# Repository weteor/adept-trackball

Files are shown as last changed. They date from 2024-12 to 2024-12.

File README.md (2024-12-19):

## xiao-mod changes:

- newly routed pcb ( [KiCAD files](hardware/electronics/adept_xiao) )
  
  - xiao rp2040 controller
  
  - two layer
  
  - components needed:
    
    - 1x seeed xiao rp2040 controller
    
    - 1x xc6206P18 LDO in SOT-23 package
    
    - 1x 100nF capacitor - 0805
    
    - 2x 1uF capacitors - 0805
    
    - 1x 10uF capacitor - 0805
    
    - 1x 39Ohm resistor - 0805
    
    - 1x 10kOhm resistor - 0805
    
    - 1x PMW3360DM-T2QU sensor (same as in orig ploopy adept)
    
    - 6x Omron D2LS-21 switches (same as in orig ploopy adept)

- modified case to support xiao dimensions ( [FreeCAD and STL files](hardware/mechanicals-xiao) )

- firmware modifications to support xiao pinout, copy [folder](firmwares/xiao_mod) to your Vial firmware folder under keyboards/ploopyco and build with: 
  `make ploopyco/adept_xiao:vial`
  or use the  `ploopyco_adept_xiao_rev1_001_vial.uf2` in the folder directly and configure the buttons in vial

---

# The Ploopy Adept Trackball

The Ploopy Adept Trackball

By some stroke of luck, you've made your way here. The Ploopy Adept Trackball. Your life will never be the same.

This repository contains all of the design and production files necessary to make a Ploopy Adept Trackball. We've also included some kick-ass documentation in the Wiki on how to get it made, assemble it, and program it.

What are you waiting for? Your new life awaits.

## QMK?!

Kits bought from the [Ploopy store](https://ploopy.co/product-category/trackball/adept/) come with QMK and VIA preloaded. Check out the Wiki for instructions on how to load new firmware onto your device. (It's super easy!)

The firmware hex file that ships with all Adepts is included in this repository as well, as `ploopyco_madromys_rev1_001_via.uf2`.

## Under what license is this released?

As per QMK's licensing requirements, the firmware for the Ploopy Adept Trackball is released under GPLv3. Hardware design files, including electronics and mechanical files, are released under OHL CERN v2-S. Check the respective directories for full license text.

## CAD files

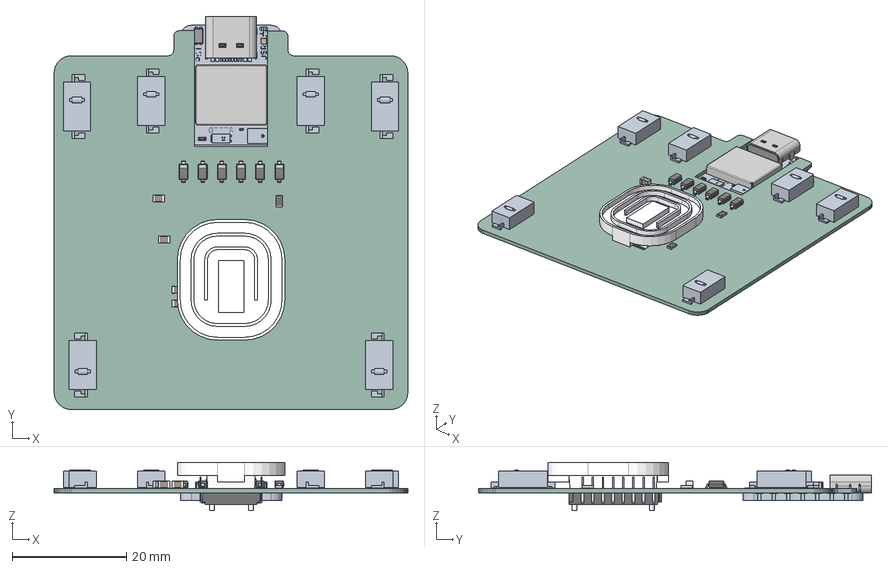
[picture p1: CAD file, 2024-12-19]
hardware/electronics/adept_xiao/adept_xiao.step
62.0 x 68.9 x 8.46 mm
_autosave-adept_xiao PCB

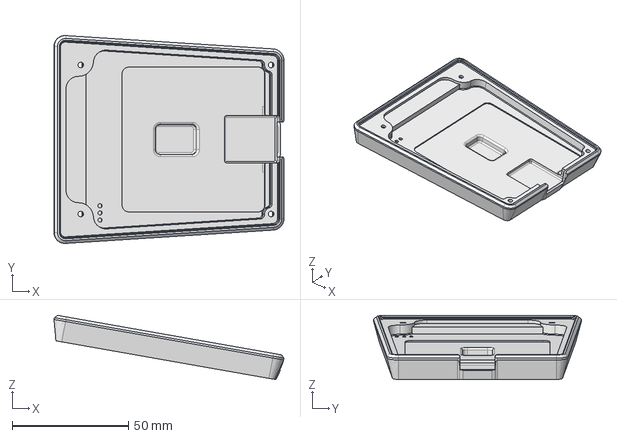
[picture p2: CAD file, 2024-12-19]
hardware/mechanicals-xiao/adept_xiao_wired.FCStd
98.8 x 89.3 x 27.6 mm

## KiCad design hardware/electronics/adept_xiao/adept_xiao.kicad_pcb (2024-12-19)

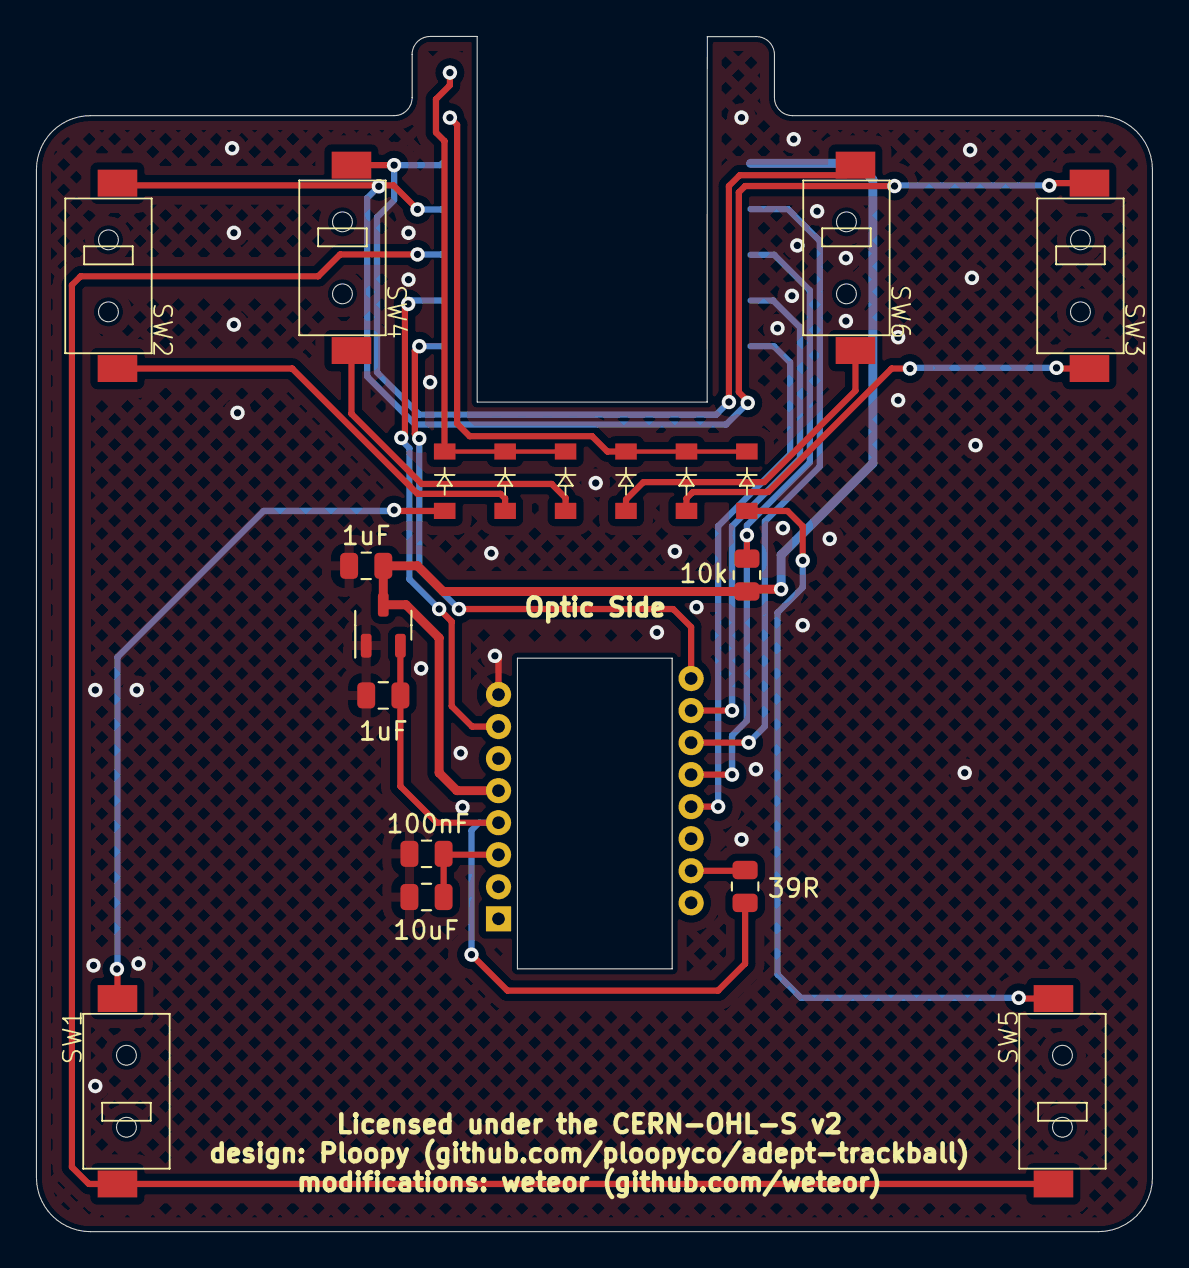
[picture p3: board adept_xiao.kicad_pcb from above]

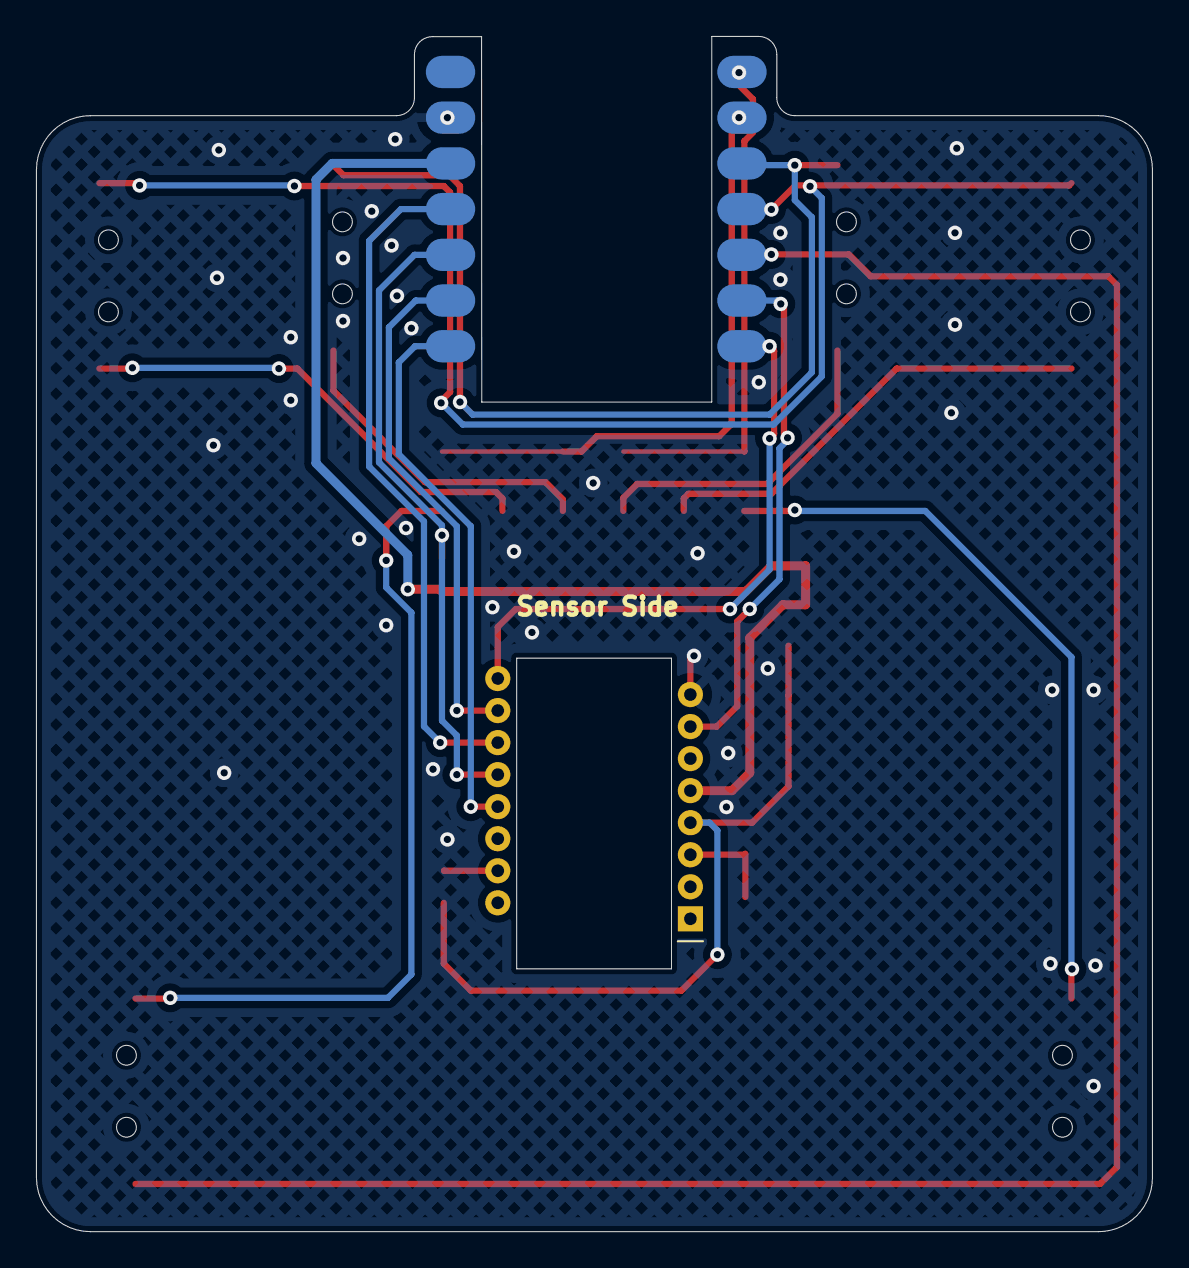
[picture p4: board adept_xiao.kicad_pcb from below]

Board: 2 copper layers, 62.0 x 66.4 mm, 21 parts (2 on the bottom side), 22 nets.

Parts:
C1, C2: 1uF; C_0805_2012Metric
C3: 100nF; C_0805_2012Metric
C4: 10uF; C_0805_2012Metric
D1, D2, D3, D4, D5, D6: D; D_SOD-123
R1: 39R; R_0805_2012Metric
R2: 10k; R_0805_2012Metric
SW1: Bottom_Left; Omron D2LS-21
SW2: Mid_Left; Omron D2LS-21
SW3: Mid_Right; Omron D2LS-21
SW4: Top_Left; Omron D2LS-21
SW5: Bottom_Right; Omron D2LS-21
SW6: Top_Right; Omron D2LS-21
U1: xiao-ble; xiao-ble-smd_upside_down
U2: PMW3360DM-T2QU; PXI-DIP-16
U3: XC6206PxxxMR; SOT-23-3

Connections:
+1V8: C2.1, R1.1, U2.4 (VDD), U3.2 (VO)
+3.3V: C1.1, R2.1, U1.12 (3V3), U2.5 (VDDIO), U3.3 (VI)
Button_Bottom: SW1.1 (A), SW5.1 (A), U1.5 (A8_SDA/0.04_H)
Button_Mid: SW2.1 (A), SW3.1 (A), U1.4 (A11/0.29)
Button_Top: SW4.1 (A), SW6.1 (A), U1.3 (A10/0.28)
Buttons_Left: D1.1 (K), D3.1 (K), D5.1 (K), U1.1 (A2/0.02_H)
Buttons_Right: D2.1 (K), D4.1 (K), D6.1 (K), U1.2 (A4/0.03_H)
GND: C1.2, C2.2, C3.2, C4.2, U1.13 (GND), U2.8 (GND), U3.1 (GND)
MISO: R2.2, U1.10 (A5_MISO/1.14), U2.12 (MISO)
MOSI: U1.11 (A6_MOSI/1.15), U2.11 (MOSI)
Motion: U1.7 (B8_TX/1.11), U2.9 (MOTION)
unnamed: D1.2 (A), SW1.2 (B)
unnamed: D2.2 (A), SW5.2 (B)
unnamed: D3.2 (A), SW2.2 (B)
unnamed: D4.2 (A), SW3.2 (B)
unnamed: D5.2 (A), SW4.2 (B)
unnamed: D6.2 (A), SW6.2 (B)
unnamed: R1.2, U2.15 (LED_P)
unnamed: C3.1, C4.1, U2.3 (VDDPIX)
SCK: U1.9 (A7_SCK/1.13), U2.10 (SCLK)
~CS: U1.8 (B9_RX/1.12), U2.13 (~CS)
~Reset: U1.6 (A9_SCL/0.05_H), U2.7 (~RESET)

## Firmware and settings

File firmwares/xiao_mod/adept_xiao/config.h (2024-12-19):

/* Copyright 2023 Colin Lam (Ploopy Corporation)
 * Copyright 2020 Christopher Courtney, aka Drashna Jael're  (@drashna) <drashna@live.com>
 * Copyright 2019 Sunjun Kim
 *
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
 * You should have received a copy of the GNU General Public License
 * along with this program.  If not, see <http://www.gnu.org/licenses/>.
 */

#pragma once

// #define ROTATIONAL_TRANSFORM_ANGLE 0
#define POINTING_DEVICE_INVERT_Y
//#define PLOOPY_DRAGSCROLL_INVERT

/* PMW3360 Settings */
#define PMW33XX_LIFTOFF_DISTANCE 0x00
#define PMW33XX_CS_PIN GP1
#define SPI_SCK_PIN GP2
#define SPI_MISO_PIN GP4
#define SPI_MOSI_PIN GP3

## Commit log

2024-12-19 add xiao mod
    [adept_xiao.kicad_pcb, adept_xiao.kicad_sch, adept_xiao.step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]
2024-12-19 fix case files
    [bottom.stl, plate.stl, top.stl]

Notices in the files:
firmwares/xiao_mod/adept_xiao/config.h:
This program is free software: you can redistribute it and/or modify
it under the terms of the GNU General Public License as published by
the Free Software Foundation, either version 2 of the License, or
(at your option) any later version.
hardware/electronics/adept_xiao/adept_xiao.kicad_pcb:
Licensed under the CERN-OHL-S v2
